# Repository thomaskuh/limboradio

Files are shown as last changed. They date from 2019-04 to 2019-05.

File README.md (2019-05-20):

# LimboRadio

DIY WEB RADIO playing music whenever you walk by or turn on the lights. Custom case, software, webinterface and PCB. Based on a RaspberryPi Zero W. I made it because there's simply no such thing to buy out there in the whole wide world ... and because I can ;)

Here's the complete guide from zero to hero. Take it as an inspiration, customize it your way or clone it 1:1. I decided to build 5 units: One for the kitchen, one for the bathroom and some for friends ... and because parts like case and PCB are way cheaper in bunches.

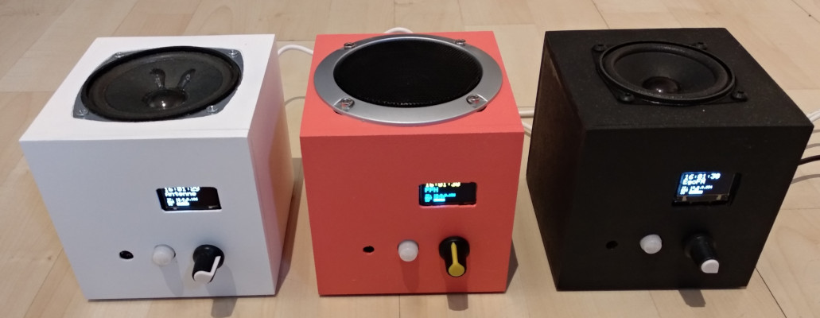
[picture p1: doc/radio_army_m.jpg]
LimboRadio Army


## Hardware

My build is based on a custom PCB placed in a selfmade wooden case. The base idea behind it is to have a PCB mounted on the backside of the front panel. All components are soldered so i don't need to mount and wire every single sensor manually somewhere in the case. I'm way to lazy to describe how i made the case since it's basically a simple cube with some holes in it. All the electronic parts are listed below and the images should be enough to get how things come together. Feel free to wire things yourself instead of using the PCB or place things in another (old) case instead.

#### PCB

Here's the PCB without components and how it looks like with all components soldered.

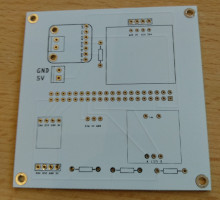
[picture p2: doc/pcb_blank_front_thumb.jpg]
PCB plain front

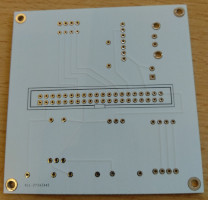
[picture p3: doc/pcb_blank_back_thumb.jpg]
PCB plain back

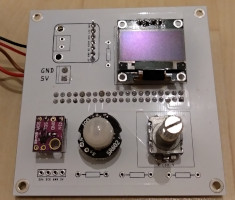
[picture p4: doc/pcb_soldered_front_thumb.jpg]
PCB with components front

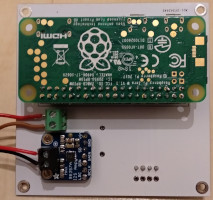
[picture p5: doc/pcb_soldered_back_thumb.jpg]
PCB with components back


#### Case

The case is basically a wooden cube with some holes for the speaker, power connector, sensors, display and rotary button.
The most interesting part is the front panel which is mounted with some small neodym magnets for easy hardware access without any screws. On it's backside you see some additional cut-outs and another wooden panel so the PCB fits perfectly.

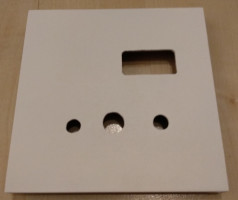
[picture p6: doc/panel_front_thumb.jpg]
Panel frontside

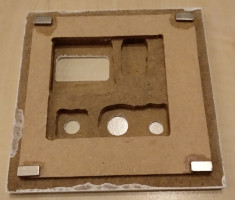
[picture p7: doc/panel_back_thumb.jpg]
Panel backside

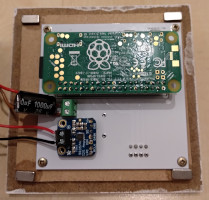
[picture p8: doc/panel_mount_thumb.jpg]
Panel with PCB mounted

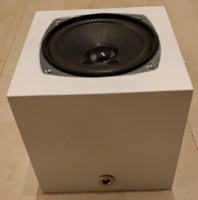
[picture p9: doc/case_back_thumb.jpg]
Case backside

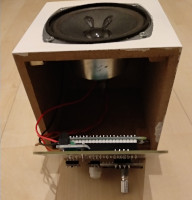
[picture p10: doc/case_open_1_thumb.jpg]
Case open 1

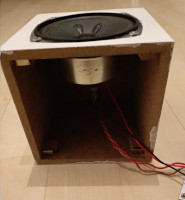
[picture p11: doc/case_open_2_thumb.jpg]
Case open 2

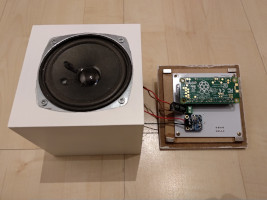
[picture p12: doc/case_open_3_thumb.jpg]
Case open 3

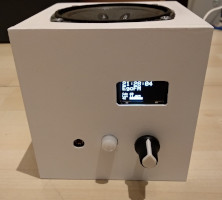
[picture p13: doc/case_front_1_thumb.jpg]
Case front 1

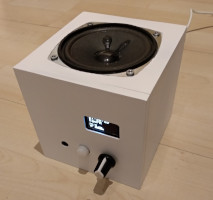
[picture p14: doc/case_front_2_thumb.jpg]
Case front 2


#### Parts
| What | Specific part/model | Price | Link |
| --- | --- | -----:| ---- |
| PCB | Gerber files in "pcb" folder  | 5€ | [AllPCB](https://www.allpcb.com) |
| Controller | Raspberry Pi Zero W | 12€ | [RaspberryPi.org](https://www.raspberrypi.org/products/raspberry-pi-zero-w/)
| I2S Amplifier | Adafruit 3W Class D MAX98357A | 7€ | [Adafruit](https://www.adafruit.com/product/3006)
| Sensor Light | GY-49 MAX44009 | 1.50€ | [AliExpress](https://aliexpress.com/wholesale?SearchText=gy-49+max44009)
| Sensor Movement | SR602 Mini PIR | 2€ | [AliExpress](https://aliexpress.com/wholesale?SearchText=SR602)
| Display | 0.96'' OLED I2C | 2€ | [AliExpress](https://aliexpress.com/wholesale?SearchText=oled+i2c+128x64)
| Knob (Volume/Channel Switch) | EC11 Rotary Button Encoder | 0.50€ | [AliExpress](https://aliexpress.com/wholesale?SearchText=ec11)
| Power Connector | DC099 DC Socket (5,5x2,1mm) | 0.50€ | [AliExpress](https://aliexpress.com/wholesale?SearchText=dc099)
| Capacitor | 25V 1000uf | 0.20€ | [AliExpress](https://aliexpress.com/wholesale?SearchText=capacitor+25v+1000uf)
| Speaker | Choose whatever you like | 5€ | [AliExpress](https://aliexpress.com/wholesale?SearchText=audio+speaker+full+range+3w)
| Case | Build yourself! | 10€ | [ExpressZuschnitt](https://expresszuschnitt.de/)
| The usual stuff | Cables, solder, screws, ... | 5€ | --- |
| | |  **~50€** | **SUM** |

## Software

The core software is written in C with an Angular Webinterface. The setup guide is based on my favorite distro: ArchLinux.

Setup a SD card using the [official arch guide](https://archlinuxarm.org/platforms/armv6/raspberry-pi#installation) for RaspberryPi Zero W. But it in your Pi and follow the guide:

```
# Ssh to your raspberry (alarm/alarm , root/root)
ssh alarm@PI_IP
su

# Finish arch setup
pacman-key --init
pacman-key --populate archlinuxarm

# Install required packages
pacman -Syu --noconfirm vim alsa-utils wiringpi i2c-tools mpd ncmpc git base-devel libwebsockets jansson wpa_supplicant cronie wget

# Set timezone
timedatectl set-timezone Europe/Berlin

# Configure custom stuff. I prefer to allow root ssh login and delete user "alarm" because I hate su/sudo overhead:
vim /etc/ssh/sshd_config
PermitRootLogin yes
userdel -f alarm

# Get LimboRadio
cd /opt
git clone https://github.com/thomaskuh/limboradio
cd limboradio

# Configure Hardware/IO/Pi/System/OS
make setup

# Build LimboRadio
make

# Install LimboRadio (Install binaries, systemd autostart)
make install

# Done. Now reboot to kick everything off.
reboot
```

The above should be quite common for those of you having some basic linux/arch skills. The only step that requires some explanation is ```make setup```. This one-liner is sets up hardware interfaces and OS services so LimboRadio could work smoothly. If you're interested in details, just take a look at the Makefile. Basically it does the following:
- Setup I2S and I2C busses (via /boot/config.txt and kernel modules)
- Setup linux sound system (alsa, i2s amp)
- Setup MPD autostart
- Setup Wifi with profile based auto-re-connect using netctl.

### WiFi configuration
To allow changes in wifi configuration without cable-connect, LimboRadio comes with the following setup:
- With "make setup" you already configured netctl for profile based wifi auto-re-connect.
- There's a fallback profile trying to connect to a wifi hotspot with SSID "yeah" and password "yeahyeah".
- There's another profile that could be configured via LimboRadio WebUI by opening http://[IP shown in display] in your browser.

So if you're still cable-connected: Simply enter the URL. Otherwise create an access point with the credentials mentioned above an you'll see LimboRadio connecting in a minute.

### Useful tools for development and troubleshooting

Alsa
```
# List audio playback devices
aplay -l

# Test playback
speaker-test -c2
speaker-test -c2 --test=wav -w /usr/share/sounds/alsa/Front_Center.wav
```

MPD
```
# ncurses based client for MPD control and testing
ncmpc
```

GPIO / I2C
```
# Read all GPIO pin states
gpio readall

# Display should be on bus 0 address 0x4a
i2cdetect -y 0

# Lux sensor should be on bus 1 address 0x3c
i2cdetect -y 1

```

### PCB design flaws / ToDos for future versions
* 3 resistors at the bottom are not required. Internal Pi pull-ups are doing just fine.
* We could remove some mm at the bottom cause it collides with ethernet port when working on a full sized Pi (instead of the zero).
* Display mount holes are a bit to small.
* Prototyping with a full sized Pi worked pretty well but after switching to the Pi zero voltage seems to break down on high volume/baselines, maybe due to no/lower capacitory on the pi zero. As a workaround I put an additional capacitor into my power screw block but there really should be dedicated place on the PCB.

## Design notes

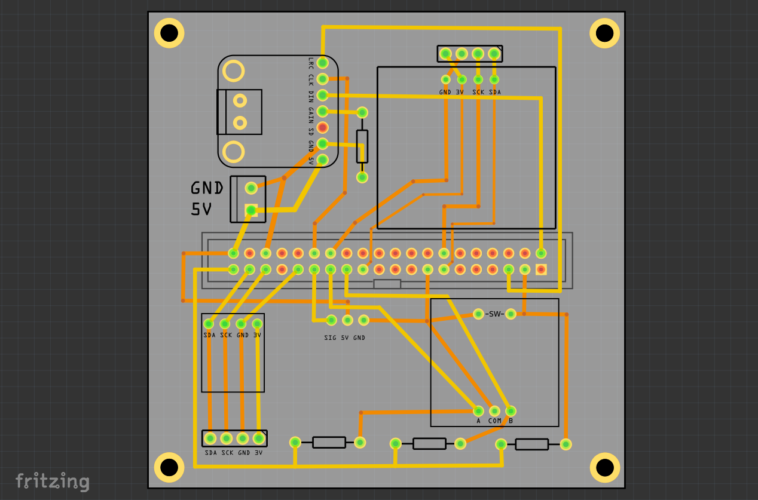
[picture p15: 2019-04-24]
doc/fritzing_screenshot.png

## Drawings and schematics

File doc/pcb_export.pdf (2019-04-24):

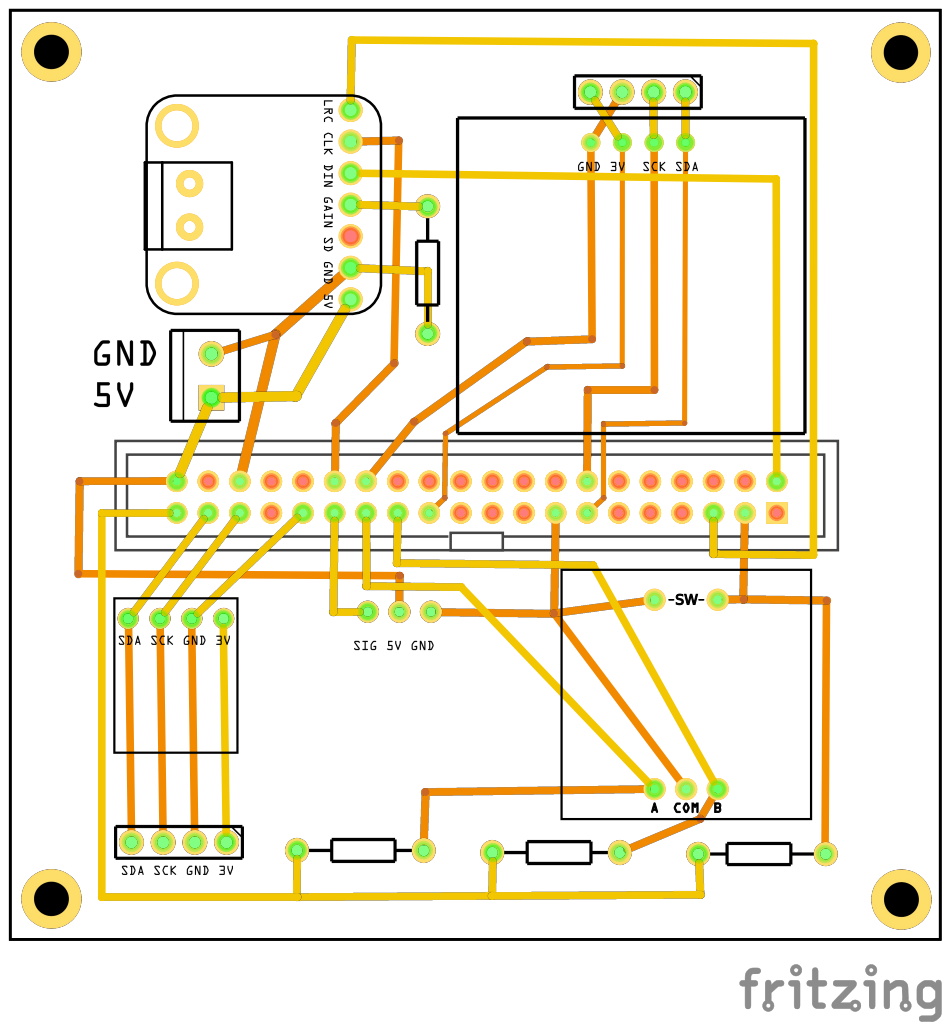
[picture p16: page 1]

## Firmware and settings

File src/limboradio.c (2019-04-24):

#include <assert.h>
#include <stdio.h>
#include <string.h>
#include <unistd.h>
#include <stdlib.h>
#include <time.h>
#include <pthread.h>

#include <signal.h>

#include <wiringPi.h>
#include <wiringPiI2C.h>

#include "lux.h"
#include "easympd.h"
#include "knob.h"
#include "countdown.h"
#include "limbonet.h"

#include "loggy.h"
#include "limboradio.h"

// Hardware:
#define HW_PIR_PIN 0            // PIR movement sensor gpio
#define HW_ROT_PIN_BTN 25       // Rotary encoder button gpio
#define HW_ROT_PIN_A 3          // Rotary encoder A gpio
#define HW_ROT_PIN_B 2          // Rotary encoder B gpio
#define HW_LUX_I2C_BUS 1        // Lux sensor i2c bus (0/1)
#define HW_LUX_I2C_ADR 0x4A     // Lux sensor i2c address on bus
#define HW_DISP_I2C_BUS 0       // Display i2c bus (0/1)
#define HW_DISP_I2C_ADR 0x3C    // Display i2c address on bus

#define LIMBO_CFG_LOCATION "/etc/limboradio.json"

char* _CORE_LOGGY = "Core";

static volatile int running = 1;

struct limbo_context ctx;

// Features:
struct countdown cntdwn;
struct lux sensorLux;

pthread_t fred_display;
pthread_t fred_status;

void stopHandler(int dummy) {
  running = 0;
}

void ctx_init() {
  // default config
  ctx.log = 1;
  ctx.mode = LIMBO_MODE_LUX;
  ctx.threshold = 5;
  ctx.timeout = 60;
  ctx.volume = 40;
  ctx.stream = 0;

  ctx.streamLen = 8;
  strcpy(ctx.streams[0].name, "EgoFM");
  strcpy(ctx.streams[0].earl, "http://mp3ad.egofm.c.nmdn.net/ps-egofm_128/livestream.mp3");
  strcpy(ctx.streams[1].name, "Antenne");
  strcpy(ctx.streams[1].earl, "http://mp3channels.webradio.antenne.de/antenne");
  strcpy(ctx.streams[2].name, "Charivari");
  strcpy(ctx.streams[2].earl, "http://rs5.stream24.net:80/stream");
  strcpy(ctx.streams[3].name, "FFH");
  strcpy(ctx.streams[3].earl, "http://mp3.ffh.de/radioffh/hqlivestream.mp3");
  strcpy(ctx.streams[4].name, "FFH 90s");
  strcpy(ctx.streams[4].earl, "http://mp3.ffh.de/ffhchannels/hq90er.mp3");
  strcpy(ctx.streams[5].name, "LoungeFM");
  strcpy(ctx.streams[5].earl, "http://stream.lounge.fm/");
  strcpy(ctx.streams[6].name, "Country");
  strcpy(ctx.streams[6].earl, "http://185.33.21.112:80/acountry_128");
  strcpy(ctx.streams[7].name, "KEXP");
  strcpy(ctx.streams[7].earl, "http://live-mp3-128.kexp.org:8000/kexp128.mp3");

  ctx.changed = 0;

  // overwrite with config file
  limboconfig_read_file(LIMBO_CFG_LOCATION);

  // initial state
  ctx.playing = 0;
  ctx.lux = 0;
  ctx.timer = 0;
  strcpy(ctx.date, "00.00.0000");
  strcpy(ctx.time, "00:00:00");
  strcpy(ctx.netinfo, "Unknown");

  loggy_info(_CORE_LOGGY, "Config -> Log: %d, Mode: %d, Threshold: %d, Timeout: %d, Volume: %d, Stream: %d.", ctx.log, ctx.mode, ctx.threshold, ctx.timeout, ctx.volume, ctx.stream);
  for(int i = 0; i < ctx.streamLen; i++) {
    loggy_info(_CORE_LOGGY, "Stream %d -> %s - %s.", i, ctx.streams[i].name, ctx.streams[i].earl);
  }
}

// Check mode vs conditions (lux, pir) and start/stop if not already in that state.
void checkStartStop() {
  int shouldPlay = 0;
  switch (ctx.mode) {
    case LIMBO_MODE_PIR:
      shouldPlay = ctx.timer > 0;
      break;
    case LIMBO_MODE_LUX:
      shouldPlay = ctx.lux >= ctx.threshold;
      break;
    case LIMBO_MODE_BOTH:
      shouldPlay = ctx.timer > 0 && ctx.lux >= ctx.threshold;
      break;
    default:
      break;
  }

  if(ctx.playing && !shouldPlay) {
    loggy_info(_CORE_LOGGY, "Playback STOP. Mode: %d, Lux: %.3f, Timer: %d.", ctx.mode, ctx.lux, ctx.timer);
    ctx.playing = 0;
    easympd_stop();
  }
  else if(!ctx.playing && shouldPlay) {
    loggy_info(_CORE_LOGGY, "Playback START. Mode: %d, Lux: %.3f, Timer: %d.", ctx.mode, ctx.lux, ctx.timer);
    ctx.playing = 1;
    easympd_start();
  }
}

void datetime_refresh() {
    time_t timeraw;
    struct tm * timeinfo;
    time ( &timeraw ); // fill time
    timeinfo = localtime ( &timeraw ); // get local
    strftime(ctx.date,80,"%d.%m.%Y", timeinfo);
    strftime(ctx.time,80,"%X", timeinfo);
}


void powertimer_callback() {
    int val = digitalRead(HW_PIR_PIN);
    loggy_debug("SensorMove", "Triggered state: %d.", val);
    if(val) countdown_set(&cntdwn, ctx.timeout);
}

void powertimer_setup() {
  if(HW_PIR_PIN == -1) {
    loggy_info("SensorMove", "Deactivated.");
  }
  else {
    loggy_info("SensorMove", "Initializing on pin %d with a timeout of %d seconds.", HW_PIR_PIN, ctx.timeout);
    pinMode(HW_PIR_PIN,INPUT);
		wiringPiISR(HW_PIR_PIN,INT_EDGE_BOTH, powertimer_callback);
	}
}

void lux_refresh() {
    ctx.lux = lux_read(&sensorLux);
    checkStartStop();
}

void* fred_display_runner(void *unused) {
  while(running) {
    datetime_refresh();
    limbodisplay_refresh(&ctx);
  }
}

void* fred_status_runner(void *unused) {
  while(running) {
    usleep(10000000);
    limbonet_info(ctx.netinfo);
    easympd_status(ctx.tagName, ctx.tagTitle);
    if(ctx.changed) {
      loggy_info("Core", "Config changed ... saving to disk.");
      ctx.changed = 0;
      limboconfig_write_file(LIMBO_CFG_LOCATION);
    }
  }
}

int main(void) {
  loggy_info(_CORE_LOGGY, "Kickin' off that LimboRadio thang...");

  signal(SIGINT, stopHandler);

  limboconfig_init();
  ctx_init();
  loggy_level(ctx.log);

  // WiringPi init
  int wiringPiRc = wiringPiSetup();
	if(wiringPiRc != 0) {
    loggy_error(_CORE_LOGGY, "GPIO init failed with RC %d. Exit.", wiringPiRc);
		return 1;
	}

  // Setup stuff we trigger manually
  limbodisplay_init(HW_DISP_I2C_BUS, HW_DISP_I2C_ADR);
  lux_init(&sensorLux, HW_LUX_I2C_BUS, HW_LUX_I2C_ADR);

  // Mpd
  easympd_setup();
  easympd_stop();
  easympd_volume(ctx.volume);
  easympd_earl(ctx.streams[ctx.stream].earl);


  // Setup stuff triggering callbacks
  knob_init(HW_ROT_PIN_A, HW_ROT_PIN_B, HW_ROT_PIN_BTN, limboradio_volume_inc, limboradio_stream_next);
  countdown_init(&cntdwn, &ctx.timer, checkStartStop, checkStartStop);
  powertimer_setup();

  web_init();

  // Thread with minimal sleep -> Refresh display.
  pthread_create (&fred_display, NULL, fred_display_runner, NULL);

  // Thread with 15sec sleep -> Refresh MPD (station, title), MPD keepalive, config persist on change.
  pthread_create (&fred_status, NULL, fred_status_runner, NULL);

  while(running) {
    usleep(200000);
    lux_refresh();
    countdown_check(&cntdwn);
  }

  loggy_info(_CORE_LOGGY, "Puttin' it down...");
  web_destroy();
  loggy_info(_CORE_LOGGY, "Ciaoi Maui!");

	return 0;
}


// ==============
// = PUBLIC API =
// ==============

struct limbo_context* limboradio_ctx() {
  return &ctx;
}

void limboradio_log(int newVal, int real) {
  if(newVal < 0 || newVal > 3 || newVal == ctx.log) {
    loggy_debug(_CORE_LOGGY, "Changing log failed. Same or illegal value detected: %d.", newVal);
    return;
  }
  ctx.log = newVal;
  if(real) {
    loggy_info(_CORE_LOGGY, "Changing log to: %d.", newVal);
    ctx.changed = 1;
  }
}

void limboradio_mode(int newVal, int real) {
  if(newVal < 0 || newVal > 2 || newVal == ctx.mode) {
    loggy_debug(_CORE_LOGGY, "Changing mode failed. Same or illegal value detected: %d.", newVal);
    return;
  }
  ctx.mode = newVal;
  if(real) {
    loggy_info(_CORE_LOGGY, "Changing mode to: %d.", newVal);
    ctx.changed = 1;
  }
}

void limboradio_volume(int newVal, int real) {
  if(newVal < 0 || newVal > 100 || newVal == ctx.volume) {
    loggy_debug(_CORE_LOGGY, "Changing volume failed. Same or illegal value detected: %d.", newVal);
    return;
  }
  ctx.volume = newVal;
  if(real) {
    loggy_info(_CORE_LOGGY, "Changing volume to: %d.", newVal);
    easympd_volume(ctx.volume);
    ctx.changed = 1;
  }
}

void limboradio_volume_inc(int volumeInc) {
    limboradio_volume(ctx.volume + volumeInc, TRUE);
}

void limboradio_stream(int newVal, int real) {
  if(newVal < 0 || newVal >= ctx.streamLen || newVal == ctx.stream) {
    loggy_debug(_CORE_LOGGY, "Changing stream failed. Same or illegal value detected: %d.", newVal);
    return;
  }
  ctx.stream = newVal;
  if(real) {
    loggy_info(_CORE_LOGGY, "Changing stream to: %d - %s - %s.", newVal, ctx.streams[newVal].name, ctx.streams[newVal].earl);
    easympd_earl(ctx.streams[newVal].earl);
    if(ctx.playing) easympd_start();
    ctx.changed = 1;
  }
}

void limboradio_stream_next() {
    int next = (ctx.stream + 1) % ctx.streamLen;
    limboradio_stream(next, TRUE);
}

void limboradio_threshold(int newVal, int real) {
  if(newVal < 0 || newVal > 10000 || newVal == ctx.threshold) {
    loggy_debug(_CORE_LOGGY, "Changing threshold failed. Same or illegal value detected: %d.", newVal);
    return;
  }
  ctx.threshold = newVal;
  if(real) {
    loggy_info(_CORE_LOGGY, "Changing threshold to: %d.", newVal);
    ctx.changed = 1;
  }
}

void limboradio_timeout(int newVal, int real) {
  if(newVal < 0 || newVal > 10000 || newVal == ctx.timeout) {
    loggy_debug(_CORE_LOGGY, "Changing timeout failed. Same or illegal value detected: %d.", newVal);
    return;
  }
  ctx.timeout = newVal;
  if(real) {
    loggy_info(_CORE_LOGGY, "Changing timeout to: %d.", newVal);
    ctx.changed = 1;
  }
}

void limboradio_streams(struct limbo_stream *input, int length, int real) {
  for(int i = 0; i < length; i++) {
    if(real) loggy_info(_CORE_LOGGY, "Changing stream %d. Name: %s, Earl: %s.", i, input[i].name, input[i].earl);
    strcpy(ctx.streams[i].name, input[i].name);
    strcpy(ctx.streams[i].earl, input[i].earl);
  }
  ctx.streamLen = length;
  if(ctx.stream >= ctx.streamLen) {
    limboradio_stream(0, real);
  }
  if(real) ctx.changed = 1;
}

void limboradio_wifi(const char *name, const char *pass, int real) {
  loggy_info(_CORE_LOGGY, "Changing wifi. Name: %s, Pass: %s.", name, pass);
  limbonet_write(name, pass);
  limbonet_reset();
}

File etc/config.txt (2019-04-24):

# See /boot/overlays/README for all available options

# I2C (lux sensor, display) - Enable i2c and set i2c_vc on to disable VideoCore processor reservation
dtparam=i2c_arm=on
dtparam=i2c_vc=on

# I2S (audio amp) - Enable i2s, driver, and mmap for dmixer
dtparam=i2s=on
dtparam=i2c=on
dtoverlay=hifiberry-dac
dtoverlay=i2s-mmap

gpu_mem=64
initramfs initramfs-linux.img followkernel

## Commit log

2019-04-24 Initial LimboRadio
    [LimboRadio.fzz, config.txt]
2019-05-04 Button debounce
